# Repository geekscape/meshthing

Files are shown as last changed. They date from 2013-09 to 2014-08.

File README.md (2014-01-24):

meshthing
=========

MeshThing module: Hardware and software repository

Current version is v2.0

Contents:
----------
-Hardware - Source files for PCB production.

-Software - Source files for testing and use.

-Resources - Additional utilities and documentation.

-Reference - Mostly datasheets.

Pinout:
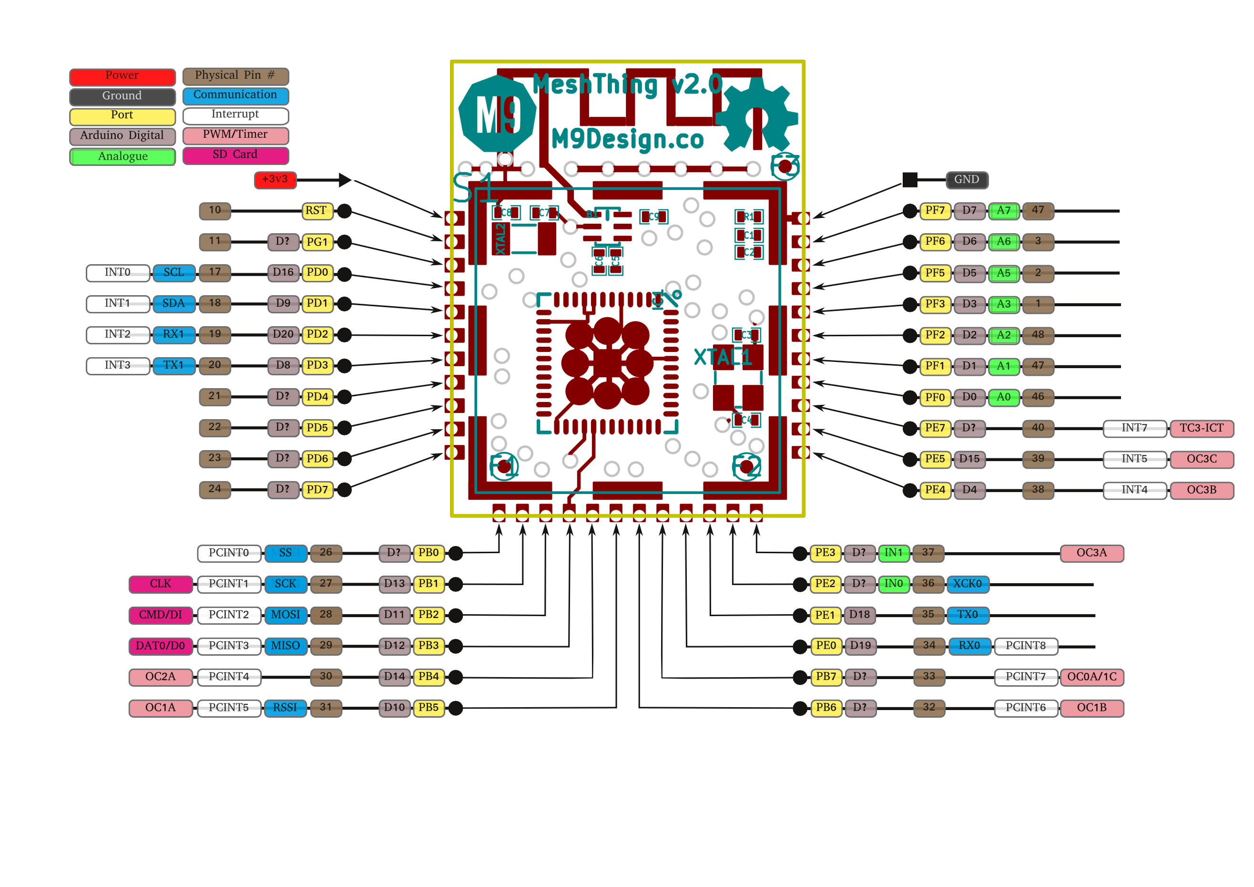
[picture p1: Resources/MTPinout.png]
Pinout


Render:

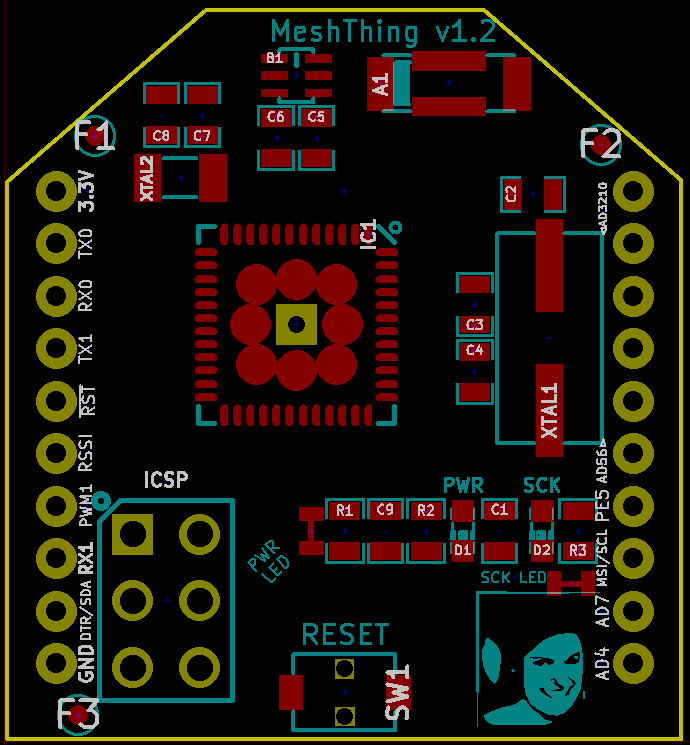
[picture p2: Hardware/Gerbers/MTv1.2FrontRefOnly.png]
MeshThing v1.2


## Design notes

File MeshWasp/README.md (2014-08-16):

meshwasp
=========

MeshWasp breakout: Hardware and software repository

This board hosts a meshthing 802.15.4 radio module and brings a selection of pins to an XBee form factor. It also includes a micro-SD card holder, reset switch, and LEDs for power and SCK signaling.

Current version is v1.0

Contents:
----------
-Hardware - Source files for PCB production.

-Resources - Additional utilities and documentation.

Pinout:
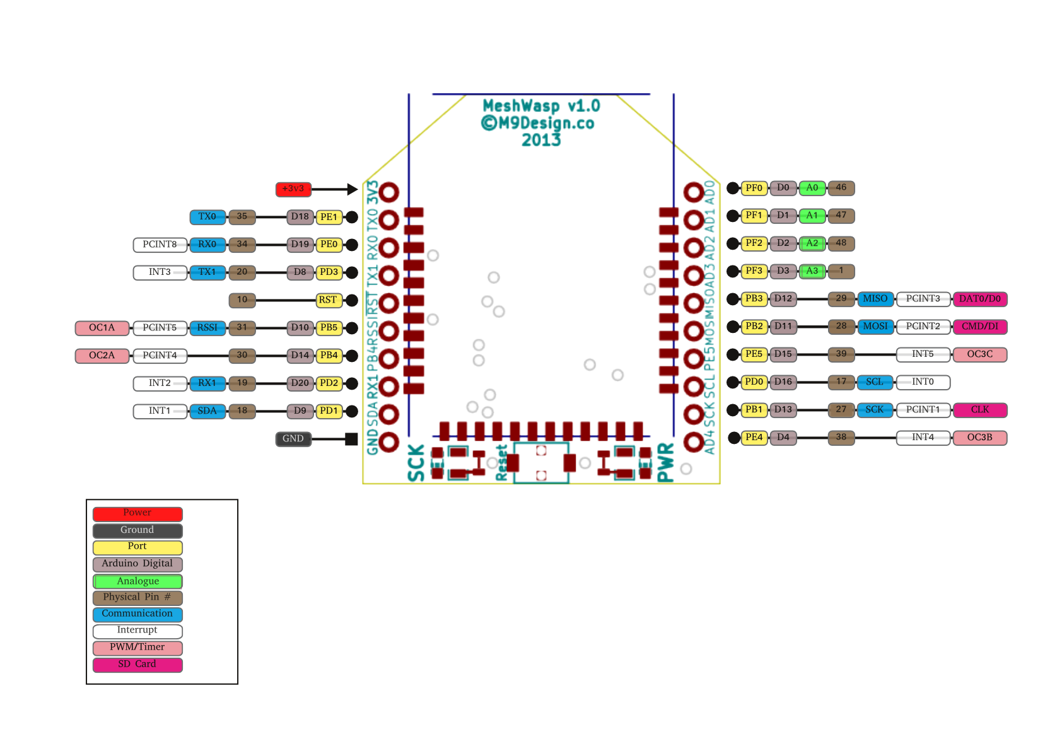
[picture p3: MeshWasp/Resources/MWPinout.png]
Pinout


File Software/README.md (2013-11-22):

This folder has software for testing and working with the MeshThing. You may require some of the software for development found in the Resources folder one level up. It has a README describing each component's use.

LEDTest should blink the green LED. Makefile should work for most situations.

SerialTest will output a continuous series of the character '.' on UART0 until it is interrupted by a keypress, showing the function of both sending and receivng serial communications. Use Makefile.

PinExercise is an Arduino sketch that will set all the I/O pins as outputs and pulse them high in order of their XBee pinout.

SDCardTest holds an Arduino sketch based on the example sketch from the Arduino IDE that will test read & write to the SDCard.

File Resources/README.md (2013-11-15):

This folder has software for developing with the MeshThing. Instructions are relevant to Linux, but should be similar for Windows or OSX.

AVRDUDERC.avrduderc is the avrprofile for the rfr2 - it should be copied and renamed to ~/.arvduderc

Arduino folder has settings and cores as needed for the Arduino environment and has it's own README.

Currently, avr-gcc doesn't compile against the target atmega2564rfr2. It is expected this will be included in future releases, but for now, one will be required to us the ATMEL toolchain. Find relevant files and instructions for use [here](http://www.atmel.com/tools/ATMELAVRTOOLCHAINFORLINUX.aspx). Note that the MeshThing uses an 8-bit processor.

Once added, you'll likely want to add the toolchain to your system PATH so it is invoked automatically.
For example, to accomplish this for bash, assuming the x64 toolchain was unpacked in your home directory:
>echo 'export PATH=~/avr8-gnu-toolchain-linux_x86_64/bin:$PATH' >> ~/.bashrc

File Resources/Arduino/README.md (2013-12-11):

This is still in progress.

Arduino Essentials
------------
You'll need the Zigduino core folder copied to <arduinoroot>/hardware/arduino/cores. - (ex. ~/arduino-1.0.5/hardware/arduino/cores/zigduino)

pins_arduino.h needs to go in a folder under <arduino root>/hardware/arduino/variants/meshthing - (ex. ~/arduino-1.0.5/hardware/arduino/variants/meshthing/pins_arduino.h)

boards.txt needs to replace the file in <arduino root>/hardware/arduino - (ex. ~/arduino-1.0.5/hardware/arduino/boards.txt)

Arduino Libraries
-------------
The libraries subfolder has modified Arduino standard libraries for use with the Meshthing.
Currently only Firmata has been modified though other libraries may work out of the box (Ex. SDCard). To use firmata:
Boards.h needs to replace existing file in <arduino root>/libraries/Firmata/Boards.h - (ex. ~/arduino-1.0.5/libraries/Firmata/Boards.h)

!!Be careful when using with a MeshUSB as the MeshUSB utilizes AD2/AD3 for battery monitoring and should be set as inputs!! Firmata seems to want to set these as outputs by default. It doesn't seem to cause any trouble, but may result in unexpected behaviour or damage.

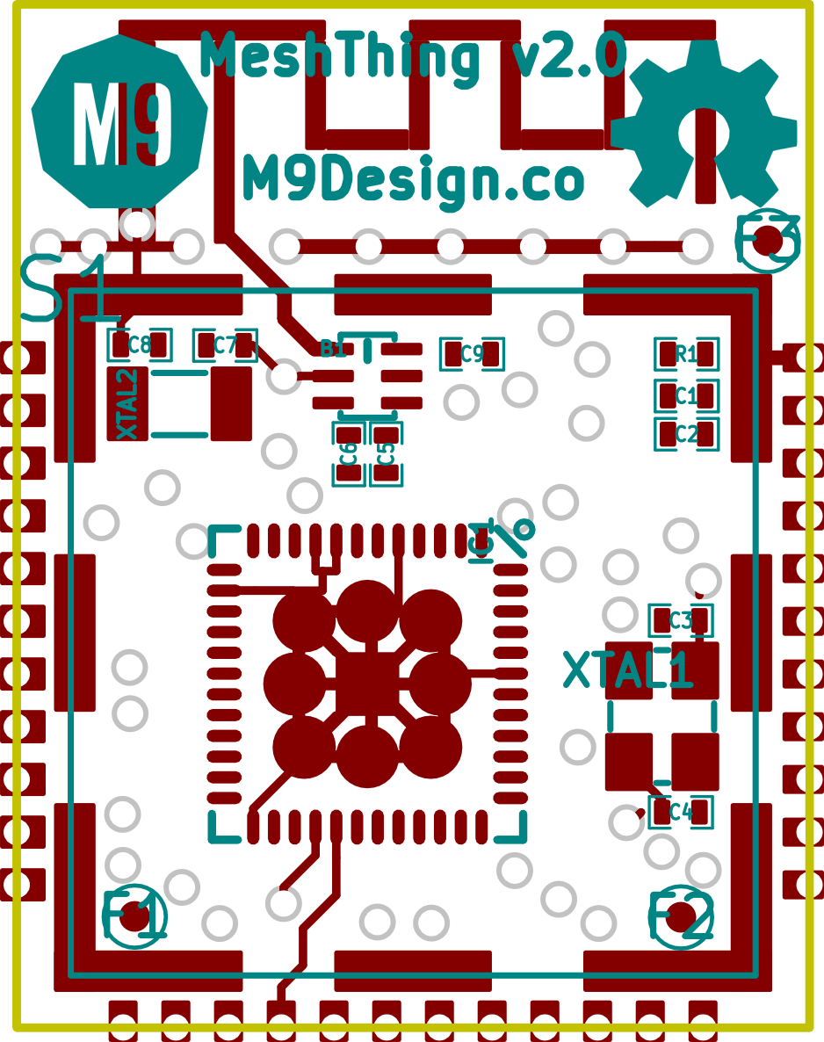
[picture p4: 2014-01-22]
Resources/MeshThing--brd.png

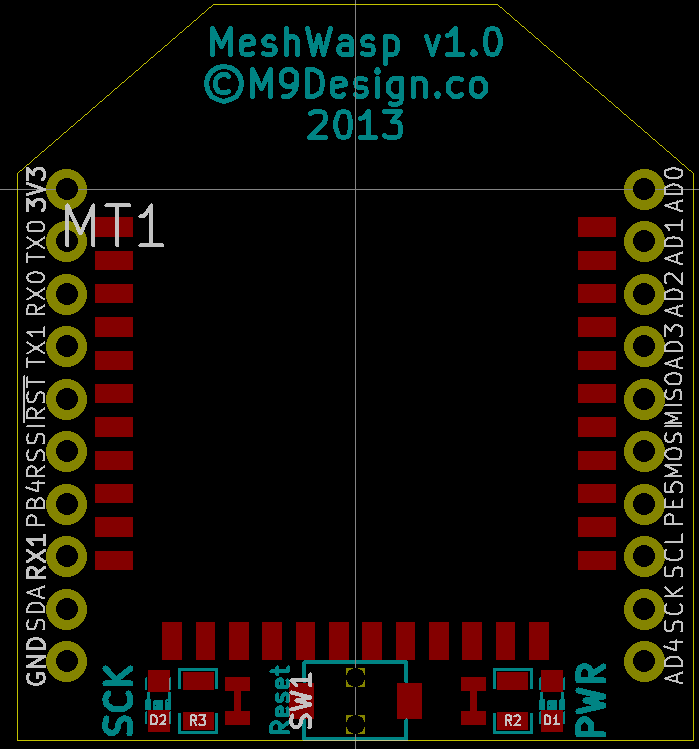
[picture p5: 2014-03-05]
MeshWasp/Resources/MeshUSB-RenderFront.png

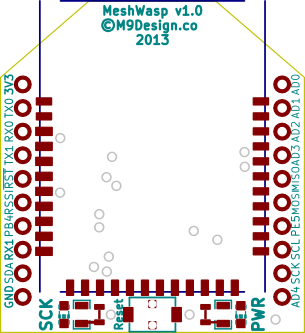
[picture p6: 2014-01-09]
MeshWasp/Resources/MeshWasp--brd.png

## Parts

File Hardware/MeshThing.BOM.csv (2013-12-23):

Part | Reference | Value | Package | Manufacturer | MFG. Part No. | Number | Link | Digikey PartNo. | Comment
Wurth Balun 748421245 | B1 | Balun | 6-Pin 0805 | Wurth Electronics Inc | 748421245 | 1 | http://www.digikey.com/product-detail/en/748421245/732-2230-1-ND/2175744 | 732-2230-1-ND
SMD Cap | C1/C2/C9 | 100n | SM0402 | Taiyo Yuden | LMK105BJ104KV-F | 3 | http://www.digikey.com/product-detail/en/LMK105BJ104KV-F/587-1227-1-ND/931004 | 587-1227-1-ND | 10v rating
SMD Cap | C3/C4 | 10p | SM0402 | Kemet | C0402C100J5GACTU | 2 | http://www.digikey.com/product-detail/en/C0402C100J5GACTU/399-1011-1-ND/411286 | 399-1011-1-ND | 50v rating
SMD Cap | C5/C6/C7/C8 | 22p | SM0402 | TDK Corporation | C1608C0G1H220J080AA | 4 | http://www.digikey.com/product-detail/en/C1608C0G1H220J080AA/445-1273-1-ND/567670 | 445-1273-1-ND | 50v rating
AVR ATMega2564RFR2 | IC1 | ATMEGA2564/1284/644RFR2 | QFN48+Pad 7mmX7mm | Atmel | ATmega2564RFR2-ZF | 1 | http://www.digikey.com/product-detail/en/ATMEGA2564RFR2-ZF/ATMEGA2564RFR2-ZF-ND/4119506 | ATMEGA2564RFR2-ZF-ND
SMD R | R1 | 10k | SM0402 | Yageo | RC0402JR-0710KL | 1 | http://www.digikey.com/product-detail/en/RC0402JR-0710KL/311-10KJRCT-ND/729365 | 311-10KJRCT-ND | 1/16w
16MHz Crystal | XTAL1 | 16MHz | TSX-3225 | Epson | TSX-3225 16.0000MF09Z-AC3 | 1 | http://www.digikey.com/product-detail/en/TSX-3225%2016.0000MF09Z-AC3/SER3628CT-ND/1802879 | SER3628CT-ND | 9pf
32.768KHz Crystal | XTAL2 | 32.768KHz |  | CTS-Frequency Controls | TF322P32K7680 | 1 | http://www.digikey.com.au/product-detail/en/TF322P32K7680/CTX1160CT-ND/2809783 | CTX1160CT-ND | 12.5pF 70kOhm
RF Shield | S1 |  | 16.5x16.5x3.6mm | Laird Technologies EMI | BMI-S-102 | 1 | http://www.digikey.com/product-detail/en/BMI-S-102/903-1007-1-ND/2175957 | 903-1007-1-ND

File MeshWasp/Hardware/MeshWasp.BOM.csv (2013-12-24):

Part | Reference | Value | Package | Manufacturer | MFG. Part No. | Number | Comment | Link | Digikey PartNo. | More Notes/Comments
SMD LED | D1 | RED LED | SM0603 | Lite-On Inc | LTST-C190KRKT | 1 | 2v/red | http://www.digikey.com/product-detail/en/LTST-C190KRKT/160-1436-1-ND/386816 | 160-1436-1-ND
SMD LED | D2 | GREEN LED | SM0603 | Lite-On Inc | LTST-C190GKT | 1 | 2v/green | http://www.digikey.com/product-detail/en/LTST-C190GKT/160-1183-1-ND/269255 | 160-1183-1-ND
SMD R | R2/R3 | 270R | SM0603 | Panasonic Electronic Components | ERJ-3GEYJ271V | 2 | .1W rating | http://www.digikey.com.au/product-detail/en/ERJ-3GEYJ271V/P270GCT-ND/134766 | P270GCT-ND
Tactile Switch | SW1 | Reset | 2.9 X 3.9 mm | Well Buying Industrial Co. Ltd. | TC007-BBA | 1 |  | http://industry.teema.org.tw/auto/PdtCmpProd_eng.asp?id=2160 |  | 2.5mm Tall
uSD Card Connector/Holder | U1 | CONN_MICROSD |  | Amphenol Commercial Products | 101-00581-59 | 1 |  | http://www.digikey.com/product-detail/en/101-00581-59/101-00581-59-1-ND/2187102 | 101-00581-59-1-ND
10 Pin 2mm Recepticles | H1/H2 | Headers | 10 pin x 1 row | SAMTEC | SAMTEC SQT-110-03-L-S | 2 | Male/female | http://www.samtec.com/ftppub/pdf/sqt_th.pdf

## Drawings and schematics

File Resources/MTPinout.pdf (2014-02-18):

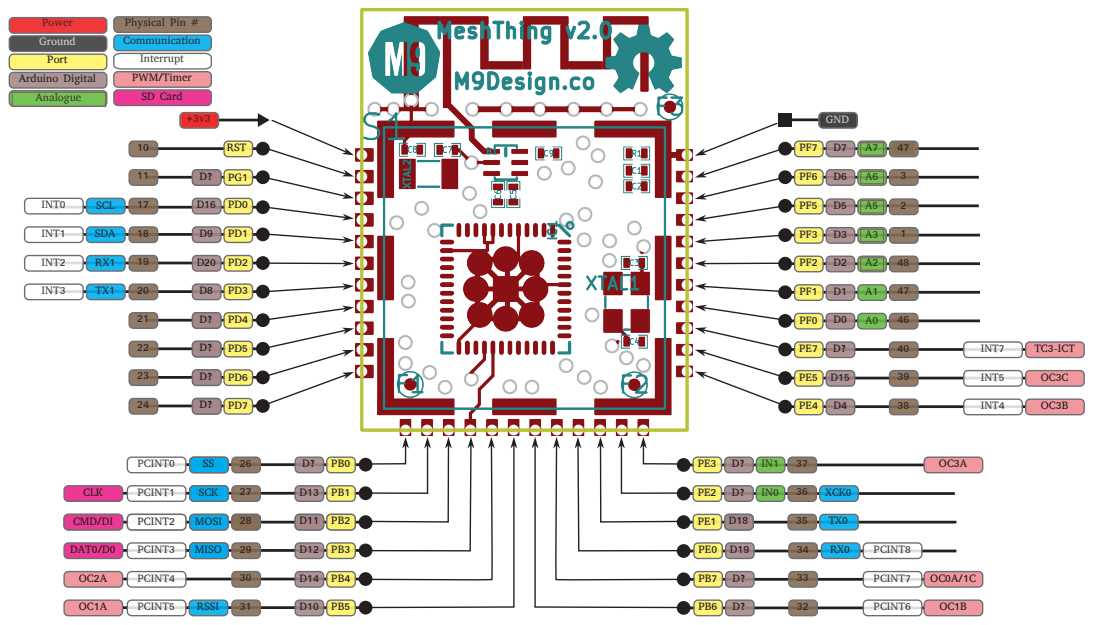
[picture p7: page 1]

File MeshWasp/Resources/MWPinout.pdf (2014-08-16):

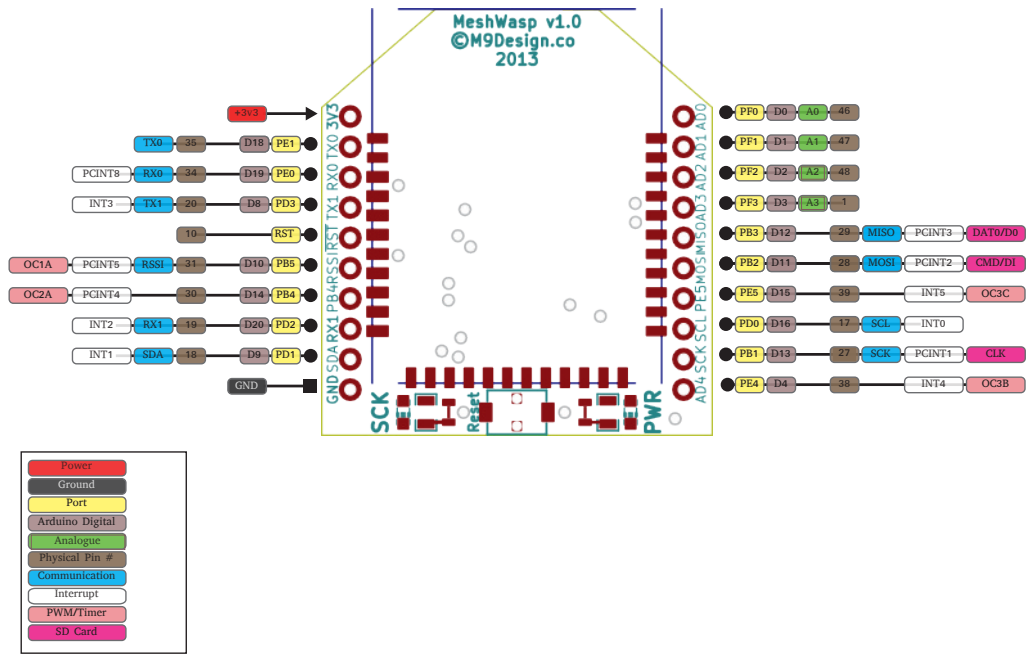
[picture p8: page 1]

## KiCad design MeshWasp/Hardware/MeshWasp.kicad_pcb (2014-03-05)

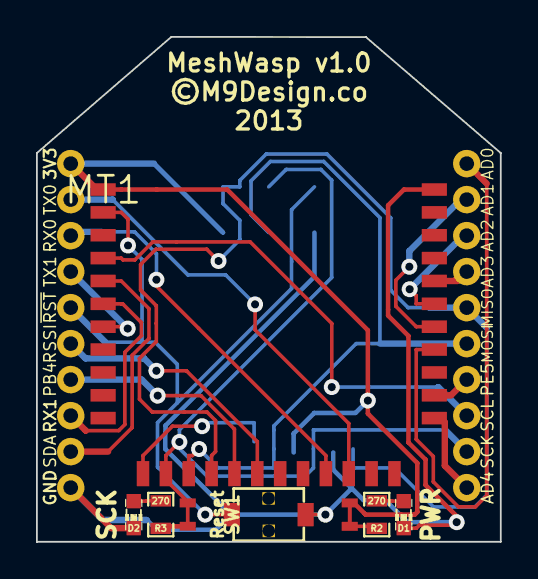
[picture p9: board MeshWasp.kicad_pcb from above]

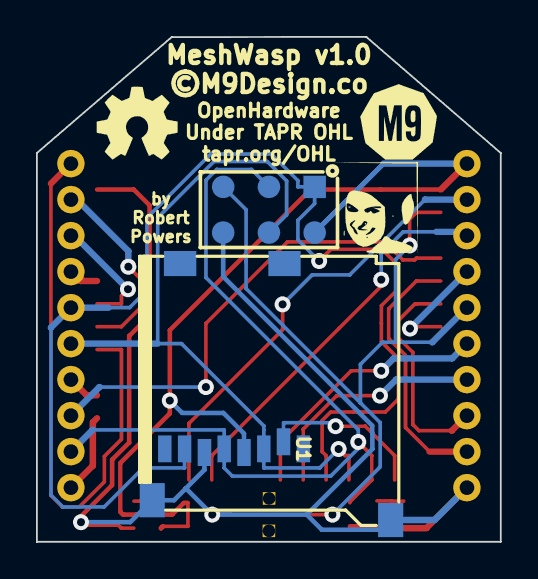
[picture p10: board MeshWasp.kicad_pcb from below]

Board: 2 copper layers, 25.8 x 28.1 mm, 14 parts (5 on the bottom side), 25 nets.

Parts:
D1, D2: LED; _MT_LED-0603
G1, G2: LOGO
H2: ICSP; _MC_pin_pad_3x2
MT1: MESHTHING; _MT_CanFootprint-34Pin
R2, R3: 270; _MT_SM0603_Resistor
SJ1, SJ2: SMTJPR; _MW_SMTJumper
SW1: RST; _MT_TC007-TactileSwitch
U1: CONN_MICROSD; _MW_microSD_3M_290805-A
U2: XBEE; _MW_XBee_Board_STD_THPads
VAL: M9Logo-flipped

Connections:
+3.3V: H2.2, MT1.1, SJ1.1, U1.4, U2.1
GND: D1.2, D2.2, H2.6, MT1.34, SW1.2, U1.6, U1.9, U2.10
MISO: H2.1, MT1.15, U1.7, U2.16
MOSI: H2.4, MT1.14, U1.3, U2.15
unnamed: D1.1, R2.2
unnamed: D2.1, R3.2
unnamed: R2.1, SJ1.2
unnamed: R3.1, SJ2.2
PB0/SS: MT1.12, U1.2
PB4: MT1.16, U2.7
PB5: MT1.17, U2.6
PE4: MT1.24, U2.11
PE5: MT1.25, U2.14
PF0: MT1.27, U2.20
PF1: MT1.28, U2.19
PF2: MT1.29, U2.18
PF3-4: MT1.30, U2.17
RX0: MT1.20, U2.3
RX1: MT1.6, U2.8
Reset: H2.5, MT1.2, SW1.1, U2.5
SCK: H2.3, MT1.13, SJ2.1, U1.5, U2.12
SCL: MT1.4, U2.13
SDA: MT1.5, U2.9
TX0: MT1.21, U2.2
TX1: MT1.7, U2.4

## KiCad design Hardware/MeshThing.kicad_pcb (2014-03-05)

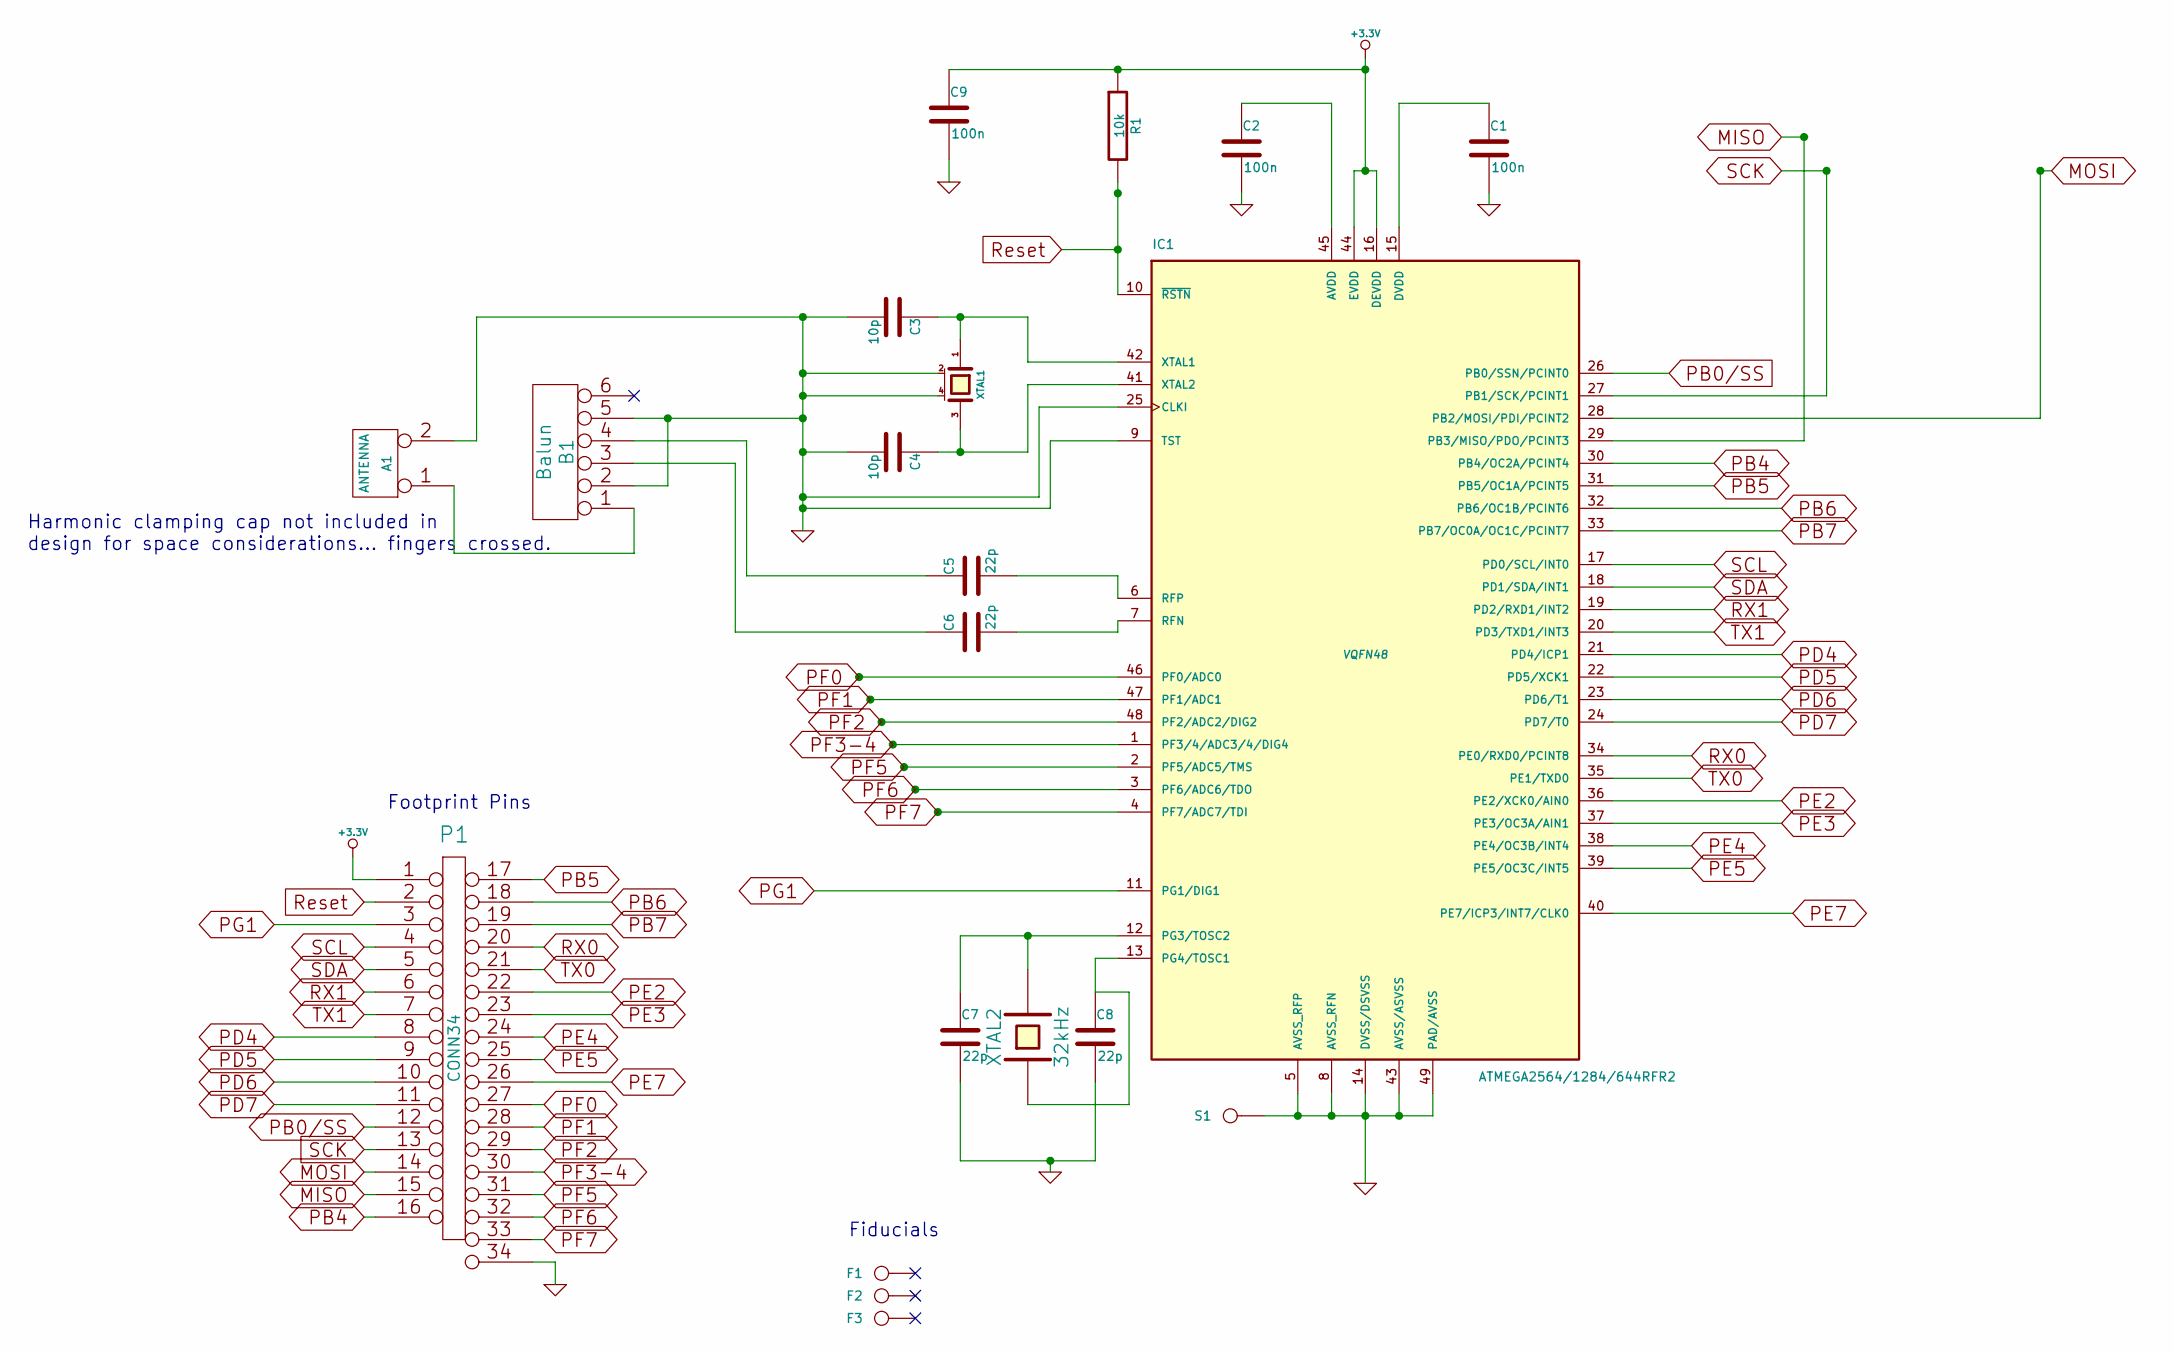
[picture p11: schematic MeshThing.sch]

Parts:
A1: ANTENNA
B1: Balun
C1, C2, C9: 100n
C3, C4: 10p
C5, C6, C7, C8: 22p
F1, F2, F3: CONN_1
IC1: ATMEGA2564/1284/644RFR2; VQFN48
P1: CONN34
R1: 10k
S1: RFShield
XTAL1: CRYSTAL_SMD-TSX3225
XTAL2: 32kHz

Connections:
+3.3V: C9.1, IC1.16 (DEVDD), IC1.44 (EVDD), P1.1, R1.1
GND: A1.2 (PM), B1.2, B1.5, C1.2, C2.2, C3.2, C4.2, C7.2, C8.2, C9.2, IC1.5 (AVSS_RFP), IC1.8 (AVSS_RFN), IC1.9 (TST), IC1.14 (DVSS/DSVSS), IC1.25 (CLKI), IC1.43 (AVSS/ASVSS), IC1.49 (PAD/AVSS), P1.34, S1.1, XTAL1.2 (case), XTAL1.4 (case)
MISO: IC1.29 (PB3/MISO/PDO/PCINT3), P1.15
MOSI: IC1.28 (PB2/MOSI/PDI/PCINT2), P1.14
unnamed: A1.1, B1.1
unnamed: B1.3, C6.1
unnamed: B1.4, C5.1
unnamed: C1.1, IC1.15 (DVDD)
unnamed: C2.1, IC1.45 (AVDD)
unnamed: C3.1, IC1.42 (XTAL1), XTAL1.1
unnamed: C4.1, IC1.41 (XTAL2), XTAL1.3
unnamed: C5.2, IC1.6 (RFP)
unnamed: C6.2, IC1.7 (RFN)
unnamed: C7.1, IC1.12 (PG3/TOSC2), XTAL2.2
unnamed: C8.1, IC1.13 (PG4/TOSC1), XTAL2.1
PB0/SS: IC1.26 (PB0/SSN/PCINT0), P1.12
PB4: IC1.30 (PB4/OC2A/PCINT4), P1.16
PB5: IC1.31 (PB5/OC1A/PCINT5), P1.17
PB6: IC1.32 (PB6/OC1B/PCINT6), P1.18
PB7: IC1.33 (PB7/OC0A/OC1C/PCINT7), P1.19
PD4: IC1.21 (PD4/ICP1), P1.8
PD5: IC1.22 (PD5/XCK1), P1.9
PD6: IC1.23 (PD6/T1), P1.10
PD7: IC1.24 (PD7/T0), P1.11
PE2: IC1.36 (PE2/XCK0/AIN0), P1.22
PE3: IC1.37 (PE3/OC3A/AIN1), P1.23
PE4: IC1.38 (PE4/OC3B/INT4), P1.24
PE5: IC1.39 (PE5/OC3C/INT5), P1.25
PE7: IC1.40 (PE7/ICP3/INT7/CLK0), P1.26
PF0: IC1.46 (PF0/ADC0), P1.27
PF1: IC1.47 (PF1/ADC1), P1.28
PF2: IC1.48 (PF2/ADC2/DIG2), P1.29
PF3-4: IC1.1 (PF3/4/ADC3/4/DIG4), P1.30
PF5: IC1.2 (PF5/ADC5/TMS), P1.31
PF6: IC1.3 (PF6/ADC6/TDO), P1.32
PF7: IC1.4 (PF7/ADC7/TDI), P1.33
PG1: IC1.11 (PG1/DIG1), P1.3
RX0: IC1.34 (PE0/RXD0/PCINT8), P1.20
RX1: IC1.19 (PD2/RXD1/INT2), P1.6
Reset: IC1.10 (~RSTN), P1.2, R1.2
SCK: IC1.27 (PB1/SCK/PCINT1), P1.13
SCL: IC1.17 (PD0/SCL/INT0), P1.4
SDA: IC1.18 (PD1/SDA/INT1), P1.5
TX0: IC1.35 (PE1/TXD0), P1.21
TX1: IC1.20 (PD3/TXD1/INT3), P1.7

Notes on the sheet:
Harmonic clamping cap not included in design for space considerations... fingers crossed.
Fiducials
Footprint Pins

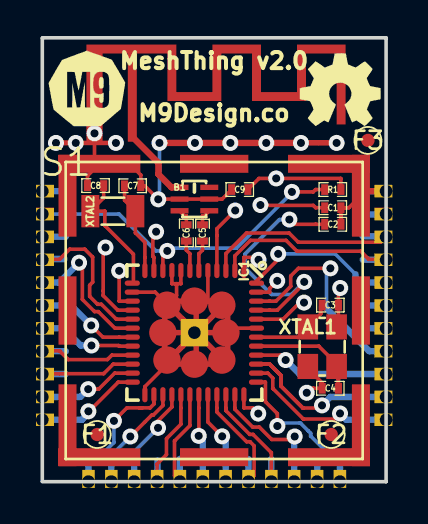
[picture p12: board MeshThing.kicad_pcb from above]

Board: 4 copper layers, 19.1 x 24.7 mm, 22 parts (1 on the bottom side), 45 nets.

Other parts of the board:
PrettyLady: PrettyLady; _MC_LOGO-PrettyLady
VAL: M9Logo-scaled

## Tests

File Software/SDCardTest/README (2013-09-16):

You have to use this file with the Arduino libraries and must have the right pins defined in pins_arduino as indicated in the comments of ReadWrite.arduino!!!

Appropriate pins_arduino.h can be found in ../Arduino/Meshthing/ - look for comments to indicate as such.

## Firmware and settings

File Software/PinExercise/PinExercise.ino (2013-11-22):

/*
  Blink
  Turns on an LED on for one second, then off for one second, repeatedly.
 
  This example code is in the public domain.
 */
 
// Pin 13 has an LED connected on most Arduino boards.
// give it a name:

int led = 13;

// the setup routine runs once when you press reset:
void setup() {                
  // initialize the digital pin as an output.
  pinMode(led, OUTPUT);
  pinMode(0, OUTPUT);  
  pinMode(1, OUTPUT);
  pinMode(2, OUTPUT);  
  pinMode(3, OUTPUT);  
  pinMode(4, OUTPUT);  
  pinMode(5, OUTPUT);
  pinMode(6, OUTPUT);  
  pinMode(7, OUTPUT);    
  pinMode(8, OUTPUT);  
  pinMode(9, OUTPUT);
  pinMode(10, OUTPUT);  
  pinMode(14, OUTPUT);  
  pinMode(15, OUTPUT);  
  pinMode(16, OUTPUT);
  pinMode(18, OUTPUT);  
  pinMode(19, OUTPUT);
  pinMode(20, OUTPUT);     
}

// the loop routine runs over and over again forever:
void loop() {

  digitalWrite(18, HIGH);   
  delay(200);               // wait for a second
  digitalWrite(18, LOW); 
  delay(200);               // wait for a second

  digitalWrite(19, HIGH);   
  delay(200);               // wait for a second
  digitalWrite(19, LOW); 
  delay(200);               // wait for a second

  digitalWrite(8, HIGH);   
  delay(200);               // wait for a second
  digitalWrite(8, LOW); 
  delay(200);               // wait for a second

  digitalWrite(10, HIGH);   
  delay(200);               // wait for a second
  digitalWrite(10, LOW); 
  delay(200);               // wait for a second
  
  digitalWrite(14, HIGH);   
  delay(200);               // wait for a second
  digitalWrite(14, LOW); 
  delay(200);               // wait for a second

  digitalWrite(20, HIGH);   
  delay(200);               // wait for a second
  digitalWrite(20, LOW); 
  delay(200);               // wait for a second
  
  digitalWrite(9, HIGH);   
  delay(200);               // wait for a second
  digitalWrite(9, LOW); 
  delay(200);               // wait for a second
  
  digitalWrite(led, HIGH);   // turn the LED on (HIGH is the voltage level)
  delay(200);               // wait for a second
  digitalWrite(led, LOW);    // turn the LED off by making the voltage LOW
  delay(200);               // wait for a second
  
  digitalWrite(0, HIGH);   
  delay(200);               // wait for a second
  digitalWrite(0, LOW); 
  delay(200);               // wait for a second
  
  digitalWrite(1, HIGH);   
  delay(200);               // wait for a second
  digitalWrite(1, LOW); 
  delay(200);               // wait for a second

  digitalWrite(2, HIGH);   
  delay(200);               // wait for a second
  digitalWrite(2, LOW); 
  delay(200);               // wait for a second
  
  digitalWrite(3, HIGH);   
  delay(200);               // wait for a second
  digitalWrite(3, LOW); 
  delay(200);               // wait for a second

  digitalWrite(6, HIGH);   
  delay(200);               // wait for a second
  digitalWrite(6, LOW); 
  delay(200);               // wait for a second

  digitalWrite(5, HIGH);   
  delay(200);               // wait for a second
  digitalWrite(5, LOW); 
  delay(200);               // wait for a second

  digitalWrite(15, HIGH);   
  delay(200);               // wait for a second
  digitalWrite(15, LOW); 
  delay(200);               // wait for a second

  digitalWrite(16, HIGH);   
  delay(200);               // wait for a second
  digitalWrite(16, LOW); 
  delay(200);               // wait for a second

  digitalWrite(7, HIGH);   
  delay(200);               // wait for a second
  digitalWrite(7, LOW); 
  delay(200);               // wait for a second

  digitalWrite(4, HIGH);   
  delay(200);               // wait for a second
  digitalWrite(4, LOW); 
  delay(200);               // wait for a second
  
  digitalWrite(led, HIGH);   // turn the LED on (HIGH is the voltage level)
  delay(200);               // wait for a second
  digitalWrite(led, LOW);    // turn the LED off by making the voltage LOW
  delay(200);               // wait for a second
}

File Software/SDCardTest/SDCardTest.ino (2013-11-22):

/*
  SD card read/write
 
 This example shows how to read and write data to and from an SD card file 	
 The circuit:
 * SD card attached to SPI bus as follows:
 ** MOSI - pin 11
 ** MISO - pin 12
 ** CLK - pin 13
 ** CS - pin 4
 
 created   Nov 2010
 by David A. Mellis
 modified 9 Apr 2012
 by Tom Igoe
 
 This example code is in the public domain.
 	 
 */
 
#include <SD.h>

File myFile;

void setup()
{
 // Open Serial communications and wait for port to open:
  Serial.begin(9600);
   while (!Serial) {
    ; // wait for Serial port to connect. Needed for Leonardo only
  }


  Serial.print("Initializing SD card...");
  // On the Ethernet Shield, CS is pin 4. It's set as an output by default.
  // Note that even if it's not used as the CS pin, the hardware SS pin 
  // (10 on most Arduino boards, 53 on the Mega) must be left as an output 
  // or the SD library functions will not work. 
   pinMode(22, OUTPUT);
   
  if (!SD.begin(17)) {
    Serial.println("initialization failed!");
    return;
  }
  Serial.println("initialization done.");
  
  // open the file. note that only one file can be open at a time,
  // so you have to close this one before opening another.
  myFile = SD.open("test.txt", FILE_WRITE);
  
  // if the file opened okay, write to it:
  if (myFile) {
    Serial.print("Writing to test.txt...");
    myFile.println("testing 1, 2, 3.");
	// close the file:
    myFile.close();
    Serial.println("done.");
  } else {
    // if the file didn't open, print an error:
    Serial.println("error opening test.txt");
  }
  
  // re-open the file for reading:
  myFile = SD.open("test.txt");
  if (myFile) {
    Serial.println("test.txt:");
    
    // read from the file until there's nothing else in it:
    while (myFile.available()) {
    	Serial.write(myFile.read());
    }
    // close the file:
    myFile.close();
  } else {
  	// if the file didn't open, print an error:
    Serial.println("error opening test.txt");
  }
}

void loop()
{
	// nothing happens after setup
}

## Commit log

2013-09-16 Commit v1.1.
    [MeshThing.AT18A100Antenna.routed.kicad_pcb, MeshThing.AT18A100Antenna.routed.sch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]
2013-10-15 Begin v1.2. Cleanup done.
    [MeshThing V1- Bill Of Materials.ods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]
2013-10-17 V1.2 nearly done. Alignment marks needed.
    [$MeshThing.sch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]
2013-10-18 More checks.
    [$MeshThing.sch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]
2013-10-18 Removing Archive folder from git tracking.
    [MeshThing V1- Bill Of Materials.ods, MeshThing.AT18A100Antenna.routed.kicad_pcb, MeshThing.AT18A100Antenna.routed.sch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]
2013-10-18 Removing Ref folder from tracking.
    [zigduino-v6c.brd, zigduino-v6c.sch]
2013-10-18 Fiducials added, refining positions.
    [MeshThing-B_Cu.gbl, MeshThing-B_Mask.gbs, MeshThing-B_Paste.gbp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]
2013-10-22 v1.2 Production.
    [MeshThing-B_Cu.gbl, MeshThing-B_Mask.gbs, MeshThing-B_Paste.gbp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]
2013-11-22 Software changes. Added pin exercise.
2013-12-22 Initial v2.0 commit.
    [MeshThing.dsn, MeshThing.kicad_pcb, MeshThing.sch]
2013-12-23 More minor fixes.
    [MeshThing.kicad_pcb]
2013-12-23 Very nearly there.
    [MeshThing-B_Cu.gbl, MeshThing-B_Mask.gbs, MeshThing-B_Paste.gbp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]
2013-12-24 MeshWasp added.
    [MeshWasp-B_Cu.gbl, MeshWasp-B_Mask.gbs, MeshWasp-B_Paste.gbp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]
2014-01-08 Initial flip done.
    [MeshWasp.dsn, MeshWasp.kicad_pcb]
2014-01-09 Mostly silks and initial documentation.
    [MeshWasp.kicad_pcb]
2014-01-09 Thicken pwr traces, mechanical relief on TH.
    [MeshWasp.kicad_pcb]
2014-01-09 Logo work.
    [MeshThing.kicad_pcb, MeshWasp.kicad_pcb]
2014-01-15 ICSP keepout recognized on MW. Silks, gerbers.
    [MeshThing-B_Cu.gbl, MeshThing-B_Mask.gbs, MeshThing-B_Paste.gbp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]
2014-01-24 Minor changes, initial positions file for MT.
    [MeshThing-B_Cu.gbl, MeshThing-B_Mask.gbs, MeshThing-B_Paste.gbp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]
2014-02-18 Removed ICSP pads.
    [MeshThing-B_Cu.gbl, MeshThing-B_Mask.gbs, MeshThing-B_Paste.gbp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]
2014-03-05 Minor silks & logo work.
    [MeshThing.kicad_pcb, MeshWasp.kicad_pcb]
2014-03-05 Positions file and footprint pad drills to .7mm.
    [MeshThing-B_Cu.gbl, MeshThing-B_Mask.gbs, MeshThing-B_Paste.gbp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]
2014-03-05 MeshWasp positions & render.
    [MeshWasp-B_Cu.gbl, MeshWasp-B_Mask.gbs, MeshWasp-B_Paste.gbp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]

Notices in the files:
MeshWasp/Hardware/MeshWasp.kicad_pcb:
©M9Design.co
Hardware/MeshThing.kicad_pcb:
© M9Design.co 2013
